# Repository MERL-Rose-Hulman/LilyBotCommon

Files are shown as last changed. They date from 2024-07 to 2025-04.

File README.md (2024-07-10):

# LilyBotCommon
LilyBotCommon is the central repository for shared components and modules used in the Lilybot project. This repository contains common parts and code that are utilized across multiple versions of Lilybot, including those powered by Microbit, Arduino Uno, Raspberry Pi Pico, and Playground Express.

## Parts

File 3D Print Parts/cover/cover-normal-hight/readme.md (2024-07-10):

`cover-normal-height` is compatible with most controllers, including UNO and PICO.

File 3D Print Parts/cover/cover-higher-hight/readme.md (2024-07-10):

`cover-higher-height` is compatible with Micro:bit

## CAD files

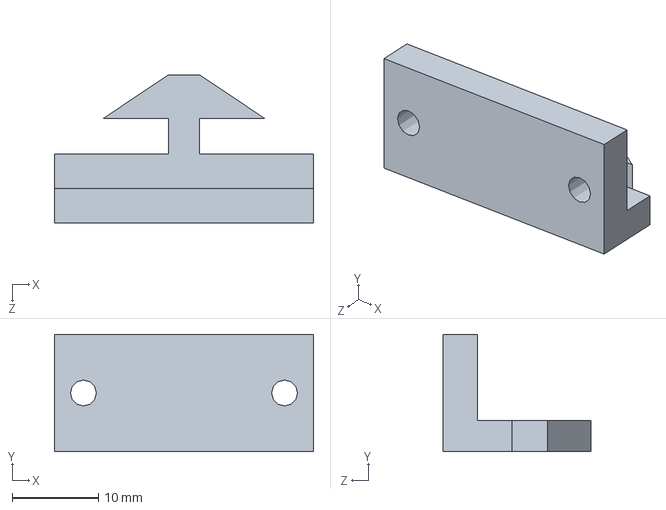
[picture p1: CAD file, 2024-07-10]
3D Print Parts/actuator/gripper/solidworks/Gripper attachment.SLDPRT
30.0 x 13.6 x 17.2 mm

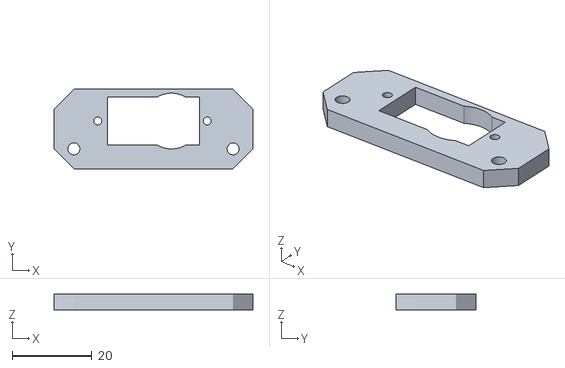
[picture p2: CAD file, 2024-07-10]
3D Print Parts/actuator/gripper/stl/servo-spacer-bigger.stl
50.0 x 20.0 x 4.00

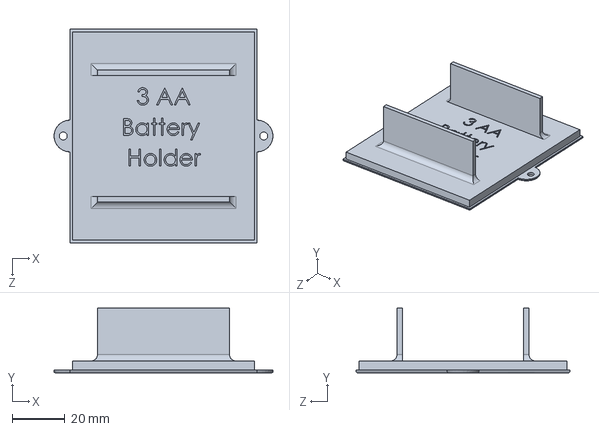
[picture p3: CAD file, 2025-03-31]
3D Print Parts/battery holders/SolidWorks/3AA Battery Holder.SLDPRT
83.0 x 24.5 x 81.0 mm

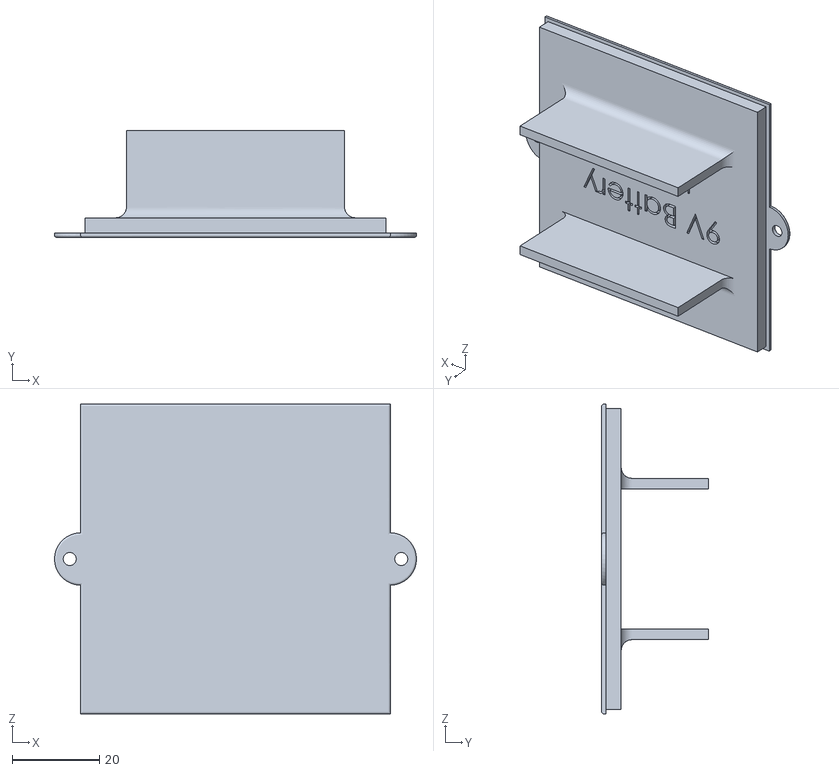
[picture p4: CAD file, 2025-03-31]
3D Print Parts/battery holders/Stl/9V Battery Holder.STL
83.0 x 24.5 x 71.0

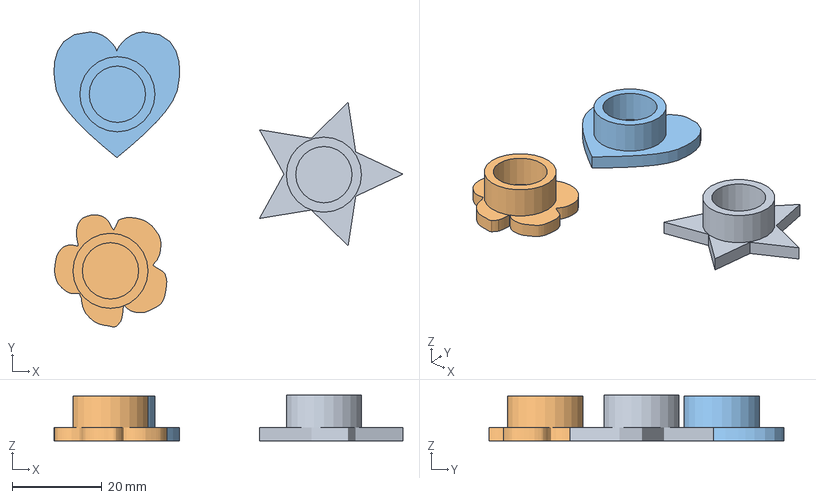
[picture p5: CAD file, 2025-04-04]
3D Print Parts/button hole covers/Printer/Button Hole Covers.3mf
77.8 x 65.7 x 10.2 mm
Star Button Hole Cover.stl
Flower Button Hole Cover.stl
Heart Button Hole Cover.stl

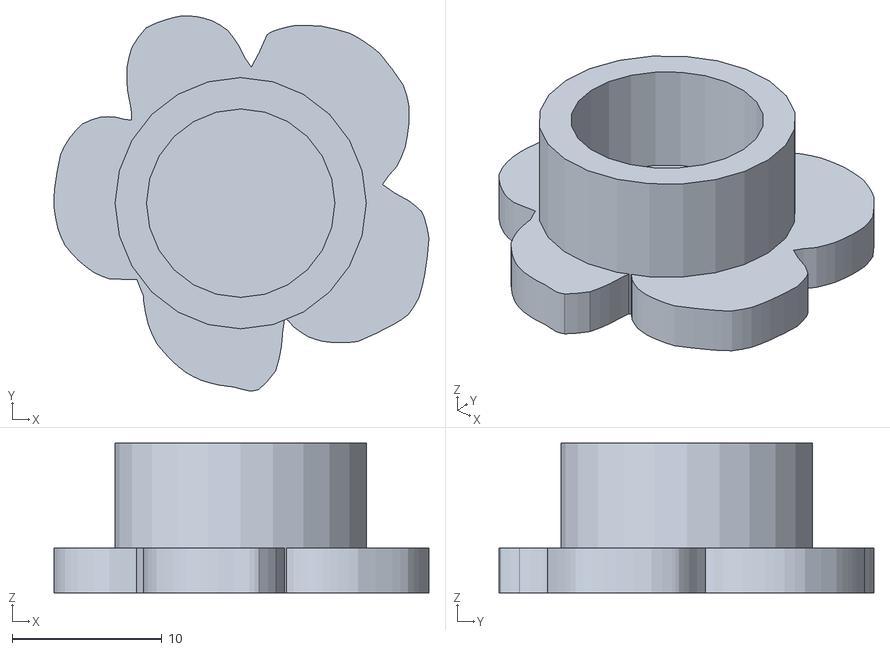
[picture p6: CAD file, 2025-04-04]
3D Print Parts/button hole covers/STL/Flower Button Hole Cover.stl
25.0 x 25.0 x 10.0

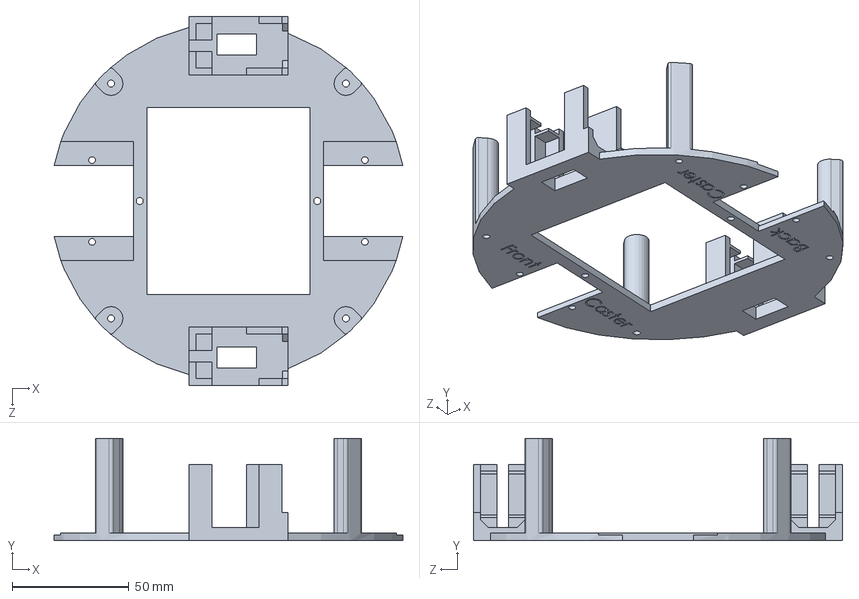
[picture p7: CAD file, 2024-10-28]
3D Print Parts/chassis/bottom/solidworks/Lily Bottom Snap Caster Lifted.SLDPRT
149.3 x 43.8 x 158.0 mm

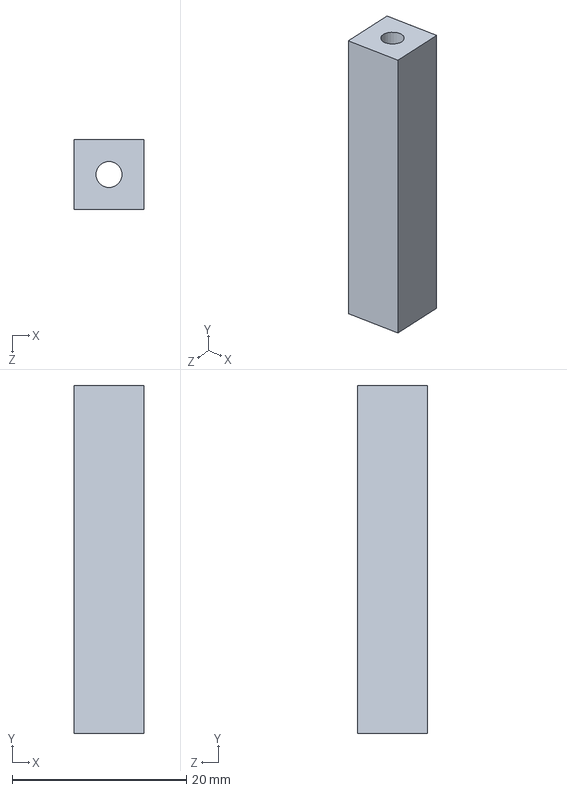
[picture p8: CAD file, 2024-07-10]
3D Print Parts/chassis/NOLONGERUSE/connection/solidworks/Lily standoffs.SLDPRT
8.00 x 40.0 x 8.00 mm

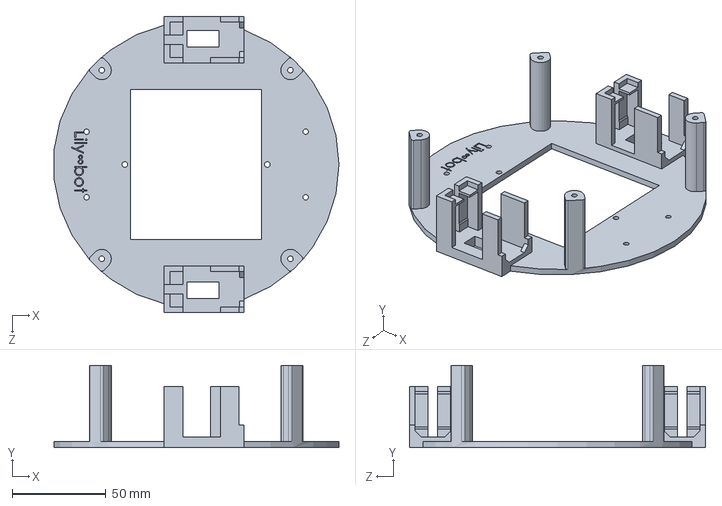
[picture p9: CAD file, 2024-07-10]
3D Print Parts/chassis/NOLONGERUSE/lower/solidworks/Lily Bottom Snap.SLDPRT
152.0 x 43.8 x 158.0 mm

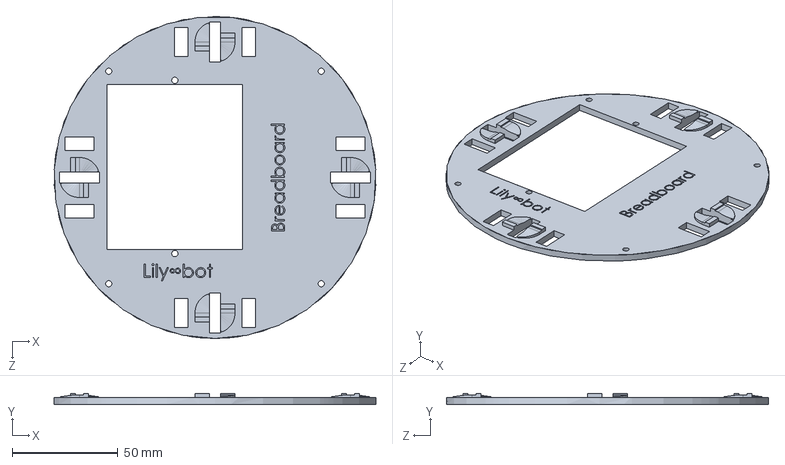
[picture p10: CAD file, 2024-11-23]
3D Print Parts/chassis/top/solidworks/Lily top Flex.SLDPRT
152.2 x 5.08 x 152.4 mm

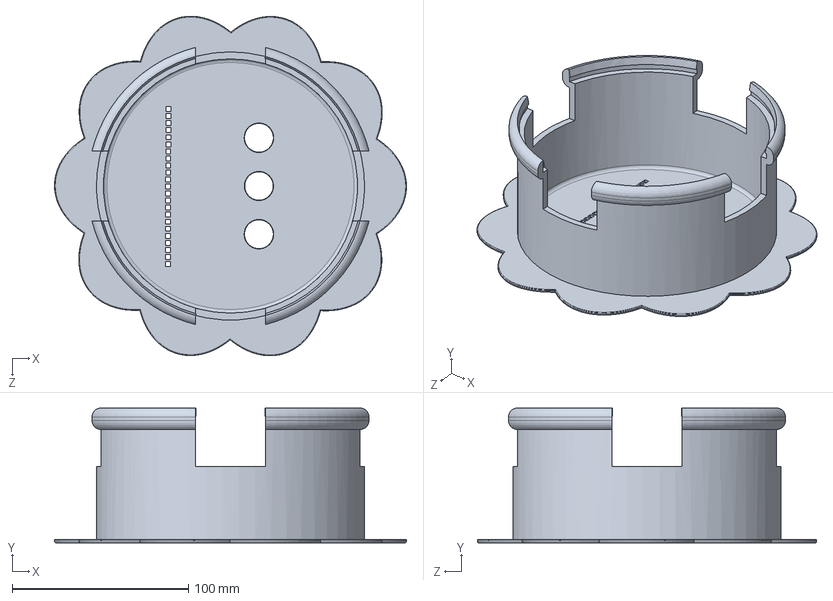
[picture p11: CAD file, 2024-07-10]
3D Print Parts/cover/cover-higher-hight/solidworks/Lily Cover v2.SLDPRT
200.0 x 76.7 x 192.9 mm

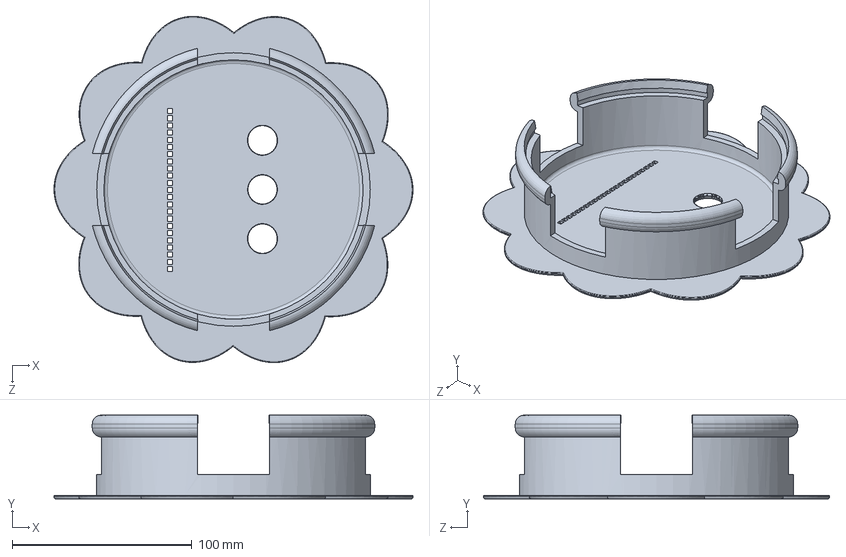
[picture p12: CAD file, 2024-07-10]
3D Print Parts/cover/cover-normal-hight/solidworks/Lily Cover.SLDPRT
200.0 x 46.7 x 192.9 mm

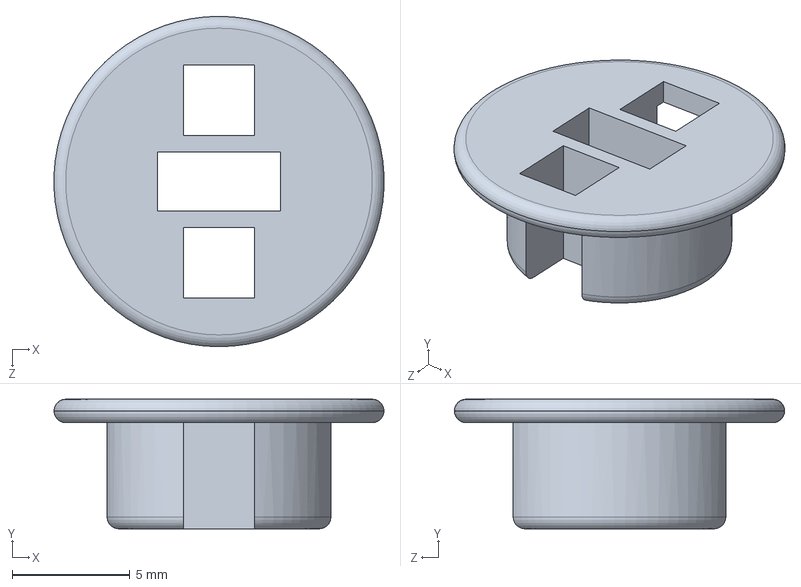
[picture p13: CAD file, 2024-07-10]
3D Print Parts/cover/NOLONGERUSED/cover tablets/solidworks/Lily Cover Hole Tablet Smaller.SLDPRT
14.0 x 5.50 x 14.0 mm

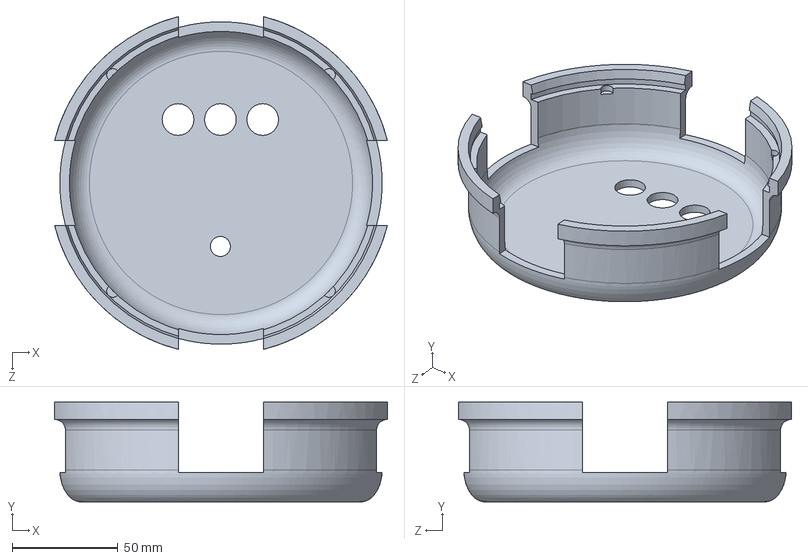
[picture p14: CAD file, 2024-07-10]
3D Print Parts/cover/NOLONGERUSED/cover v1/solidworks/Lily Cover.SLDPRT
157.4 x 47.2 x 157.4 mm

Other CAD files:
3D Print Parts/NOLONGERUSE/motor_mount/solidworks/Motor Mount.SLDPRT
3D Print Parts/NOLONGERUSE/motor_mount/stl/Motor Mount Thick.STL
3D Print Parts/sensor_mount/IR/solidworks/IR sensor Attachment _v2.SLDPRT
3D Print Parts/NOLONGERUSE/motor_mount/solidworks/Motor Mount_V2.SLDPRT
3D Print Parts/NOLONGERUSE/motor_mount/stl/Motor Mount Thin.STL
3D Print Parts/actuator/gripper/stl/GripperAttachment.STL
3D Print Parts/actuator/gripper/stl/finger-bushing-thin.stl
3D Print Parts/actuator/gripper/stl/finger-left-thin.stl
3D Print Parts/actuator/gripper/stl/finger-pad.stl
3D Print Parts/actuator/gripper/stl/finger-right-thin.stl
3D Print Parts/actuator/gripper/stl/gripper-base-thin.stl
3D Print Parts/actuator/gripper/stl/servo-gear.stl
3D Print Parts/actuator/gripper/stl/top-plate-fixed.stl
3D Print Parts/battery holders/SolidWorks/4AA Battery Holder.SLDPRT
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

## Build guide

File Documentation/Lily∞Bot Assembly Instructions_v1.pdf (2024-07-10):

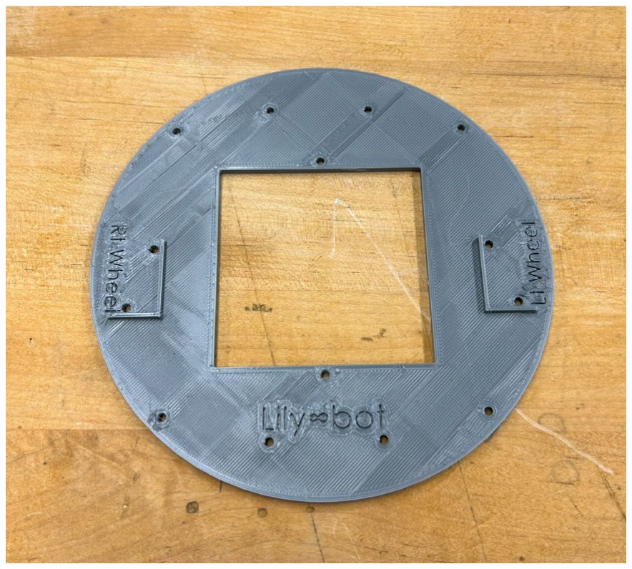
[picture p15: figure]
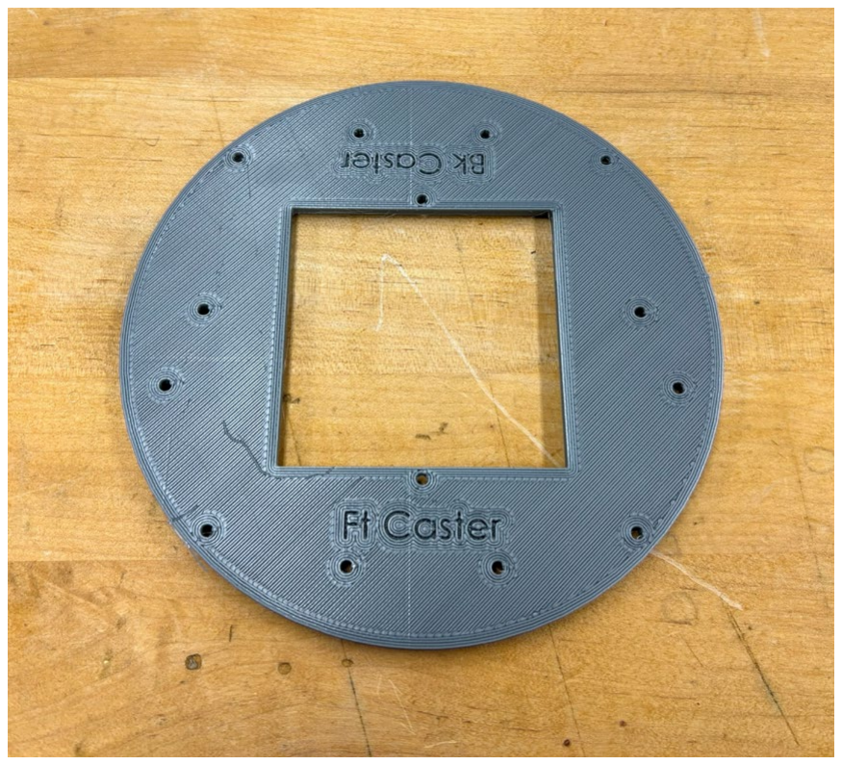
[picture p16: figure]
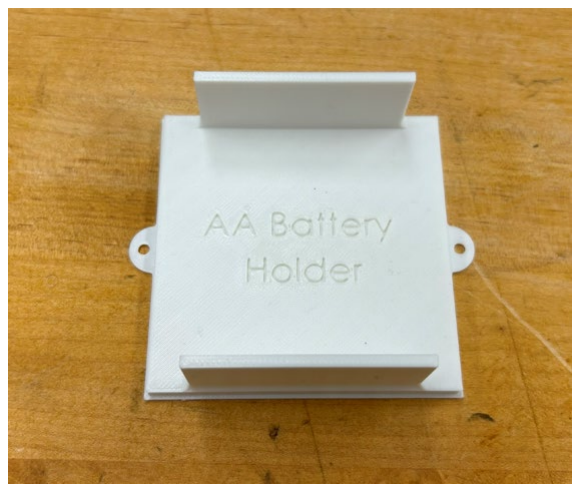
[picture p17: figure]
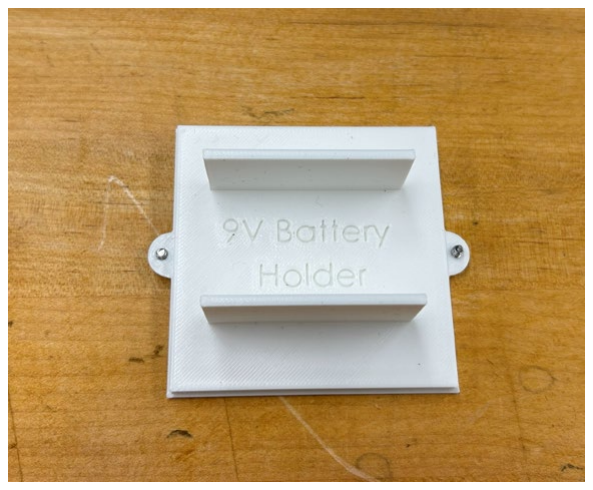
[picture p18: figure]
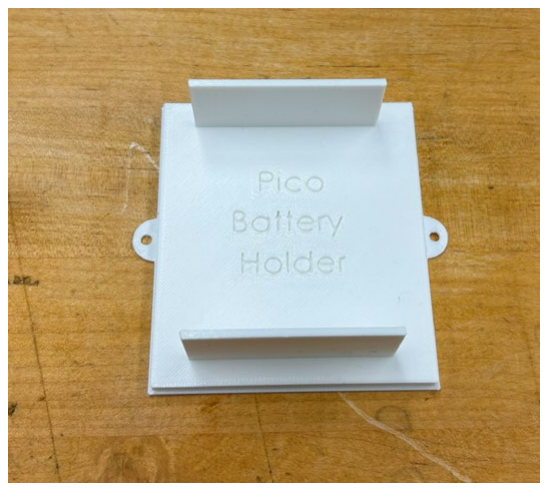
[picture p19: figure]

Version 1: 12/1/23 | Building Lily∞Bot | 1

# Building Lily∞Bot

1. Start by laying out the bottom of the chassis and the battery module that corresponds to your

controller. The AA battery holder is for the Arduino Uno, the 9V battery holder is for the

Microbit, and the Pico battery holder is for the Raspberry Pi Pico.

Figure 1: Top (left) and bottom (right) faces of the bottom chassis

Figure 2: AA Battery holder for the Arduino Uno, 9V battery holder for the Microbit, and the battery

holder for the Raspberry Pi Pico
2. Now that you have your bottom chassis and the right battery holder, let’s start assembling.

This guide uses the 9V battery pack module for its robot. Place your bottom chassis with the

Rt Motor and Lt Motor text facing up and the Ft Caster and Bk Caster text facing down. Take your battery holder and slot it into the chassis from the bottom such that the mounting holes

line up with the holes in the chassis. Figure 3 shows the robot base with a 9V battery pack

module screwed into it.

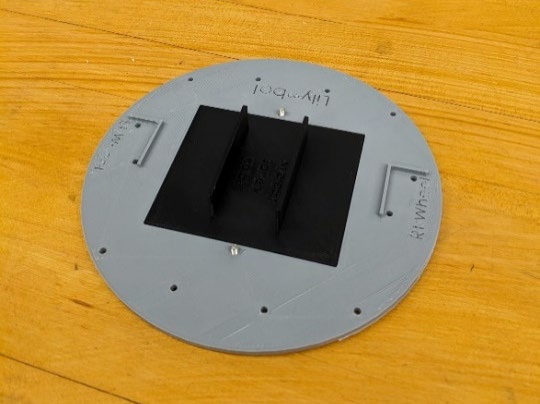
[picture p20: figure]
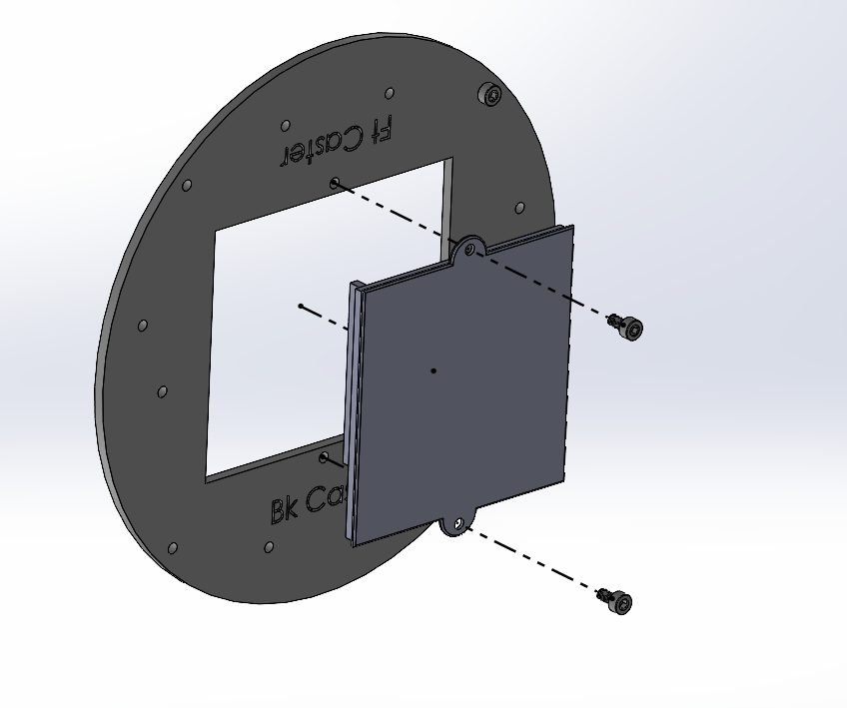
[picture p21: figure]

Figure 3: Bottom base with battery pack module.
3. Get the left and right 3d printed motor mounts and the 2 motors. If not attached, you will

need to use two 10 mm (about 0.39 in) M3 machine screws to attach each motor to the motor

mount. Make sure that the red and black wires point toward the long-slotted end of the

motor mount. Figure 4 shows the right and left motors inserted into the motor mounts with

the 10 mm screws. The figure also shows 2 wheels and four 8 mm (about 0.31 in) M3

mounting screws for attaching the motor mount to the base of the robot.

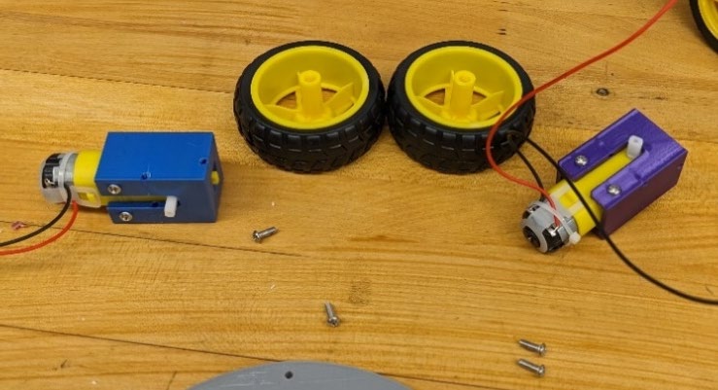
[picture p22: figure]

Figure 4: Wheels, Motors, and Screws.

4. Figure 5 shows the various batteries inserted into their corresponding battery holders. Each

battery pack may be inserted at any time during the robot assembly process. Note that the

robot will ship without batteries.

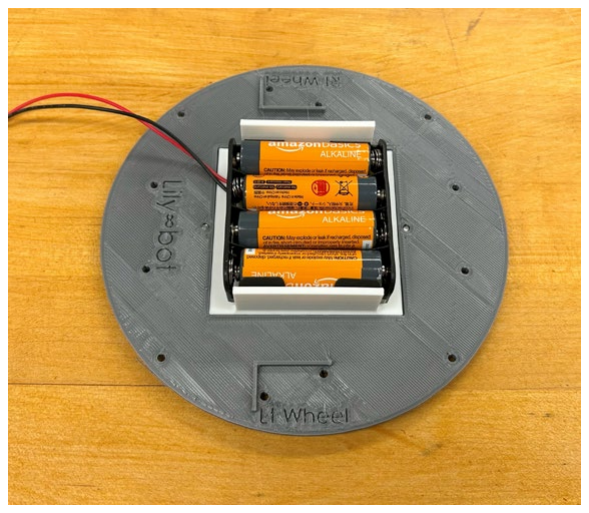
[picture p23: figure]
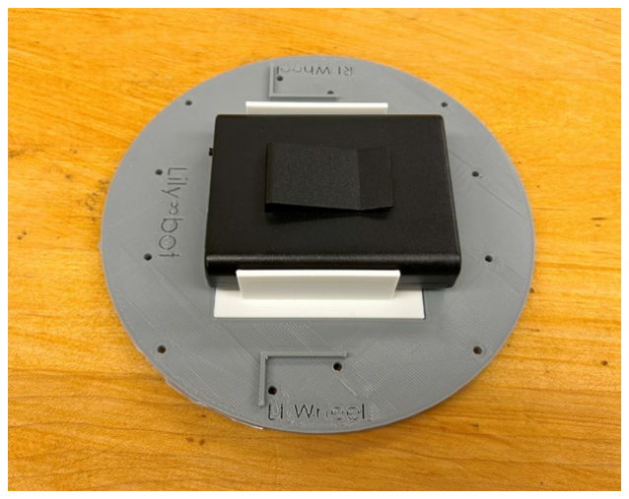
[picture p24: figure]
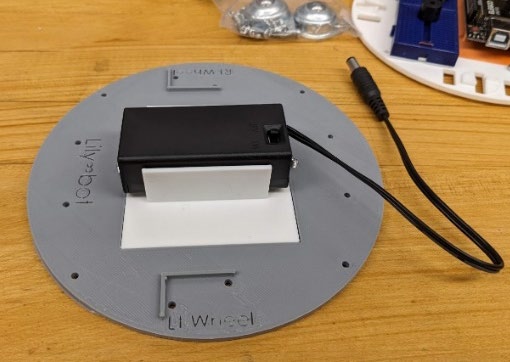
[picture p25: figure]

Figure 5: 9V, Pico, and AA battery packs inserted in battery pack module on robot base
5. The side of each motor should have either an R or an L engraved on it. Starting with the left

motor, place it on the left side of the base (also engraved) such that the wires face the inside

of the robot and the mounting holes on the motor line up with the base. Take one of your

mounting screws, and, using a Phillips head screwdriver, thread it into the bottom of the base

until the head is flush with the base. Repeat with the other screw until the motor is securely

in place. Repeat with the other motor. Figure 6 shows mounting the motors to the robot base.

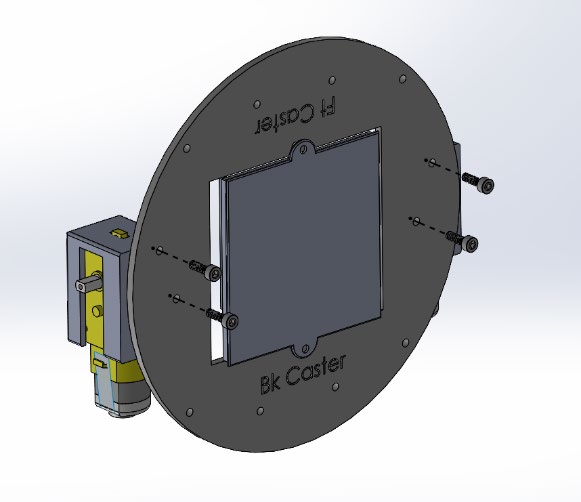
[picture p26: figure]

Figure 6: Attaching the motors to the robot base.
6. Collect 2 caster wheels, 4 M3 screws, 4 M3 nuts, and 4 M3 lock washers as shown in Figure

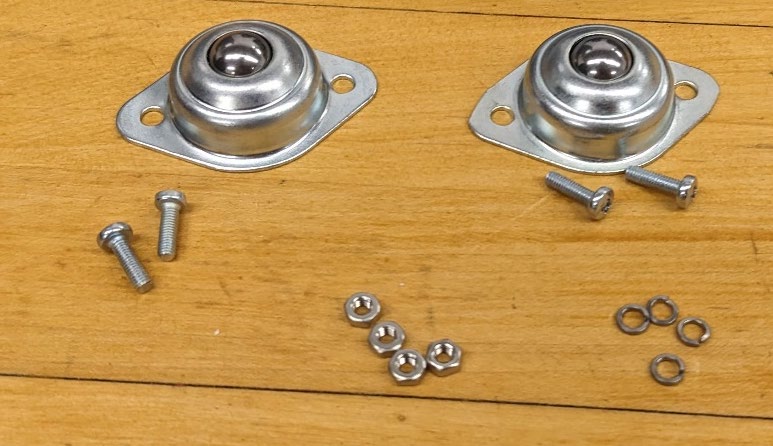
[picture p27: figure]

Figure 7: 2 caster wheels, 4 M3 8 mm (about 0.31 in) screws, 4 M3 lock washers, 4 M3 washers
7. Mount the front caster wheel (labeled on bottom of base) by taking the wheel and placing its

flat side against the bottom of the base. Take each screw and push it through the wheel and

base. Take your lock washer (one for each screw) and place it on the screw. Finally, thread

the nut onto the screw, using a Phillips head screwdriver and appropriate wrench to firmly

secure the wheel in place. Repeat with back caster wheel. Figure 8 shows the steps to attach

the two cater wheels to the bottom robot chassis.

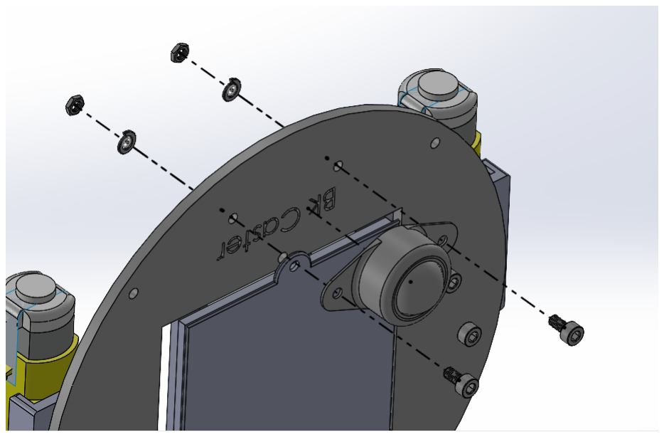
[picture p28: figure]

Figure 8: Attach the caster wheel to the bottom robot chassis using 2 screws, 2 nuts, and 2 lock washers
8. Collect 4 standoffs and 4 8mm (about 0.31 in) M3 machine screws as shown in Figure 9.

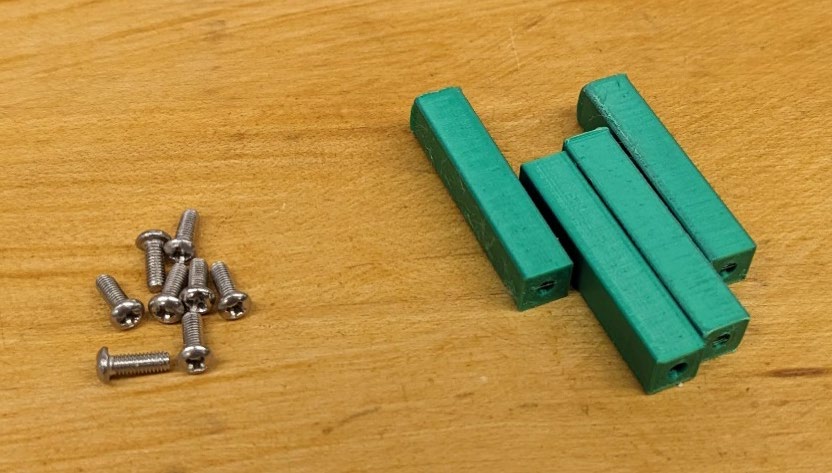
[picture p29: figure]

Figure 9: 4 standoffs and 8 8 mm M3 screws
9. Take one standoff and position it above one of the 4 holes on the outside of the bottom

piece. Take one screw and thread it through the hole, into the standoff from the bottom

of the base. Screw it in carefully, making sure the screw is perpendicular to the base. If

you feel too much resistance, take it out and try again making sure the screw is straight.

Figure 10 shows an example of connecting one standoff to the robot bottom chassis.

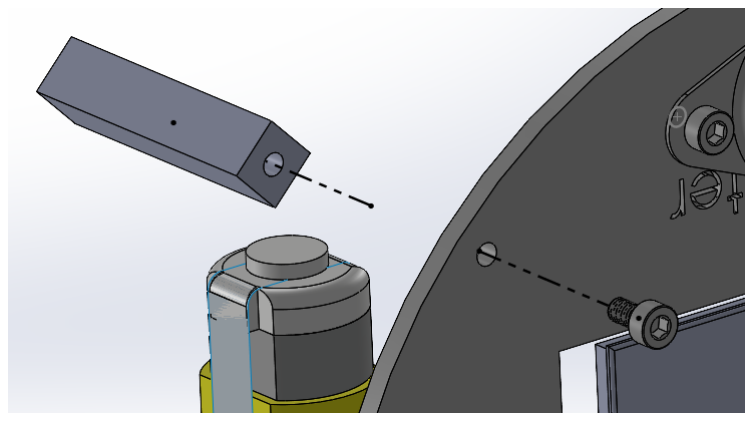
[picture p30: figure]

Figure 10: Connect one standoff to the robot bottom chassis with an 8 mm M3 screw
10. Repeat with the other standoffs, only screwing them in from the base. You should have

4 screws left over when you are done.

11. Retrieve the top chassis for the robot as shown in Figure 11 and attach the

corresponding controller module to it using 2 screws.

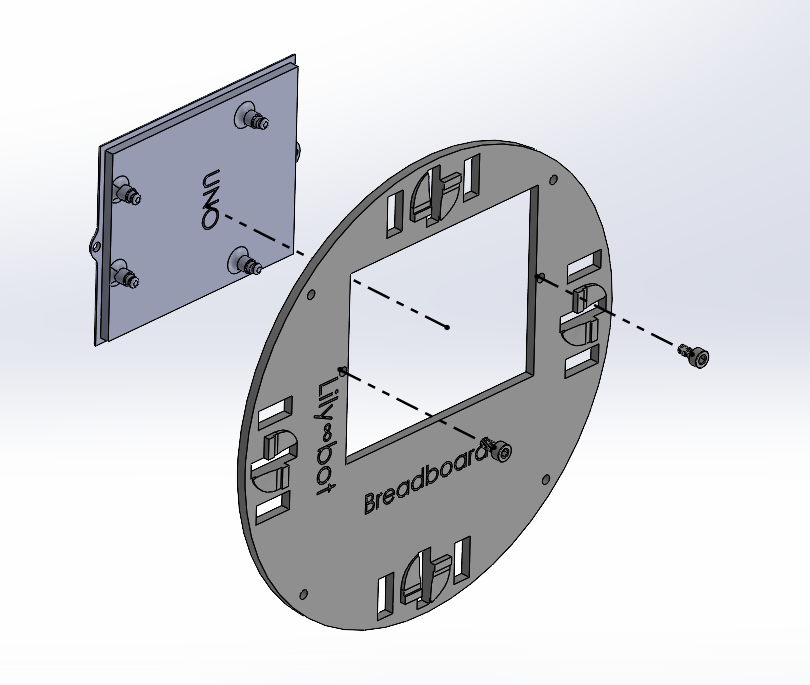
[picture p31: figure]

Figure 11: Screwing the controller mount into the top chassis
12. Some Pico and Uno controller mounts are snap-ons and some have holes to screw into.

For the former, carefully snap the controller in place, lining the holes of the controller

with the mounts and pressing slowly. For the latter, use two 6 mm screws to mount the

controller. Figure 12 shows the Pico and Uno attached to the module with screws.

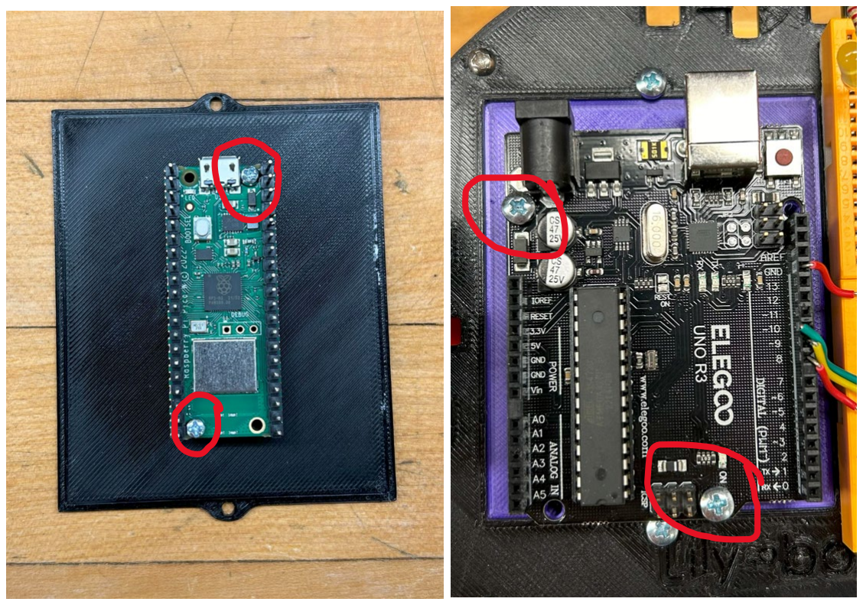
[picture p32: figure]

Figure 12: Pico and Uno microcontrollers screwed into their mounts

13. To install the Microbit, you need to carefully slide the board into the two grooves on the

mount. Push it through such that the board is roughly centered on the mount. Then attach

the vertical board by slotting it into the gold end of the horizontal board.

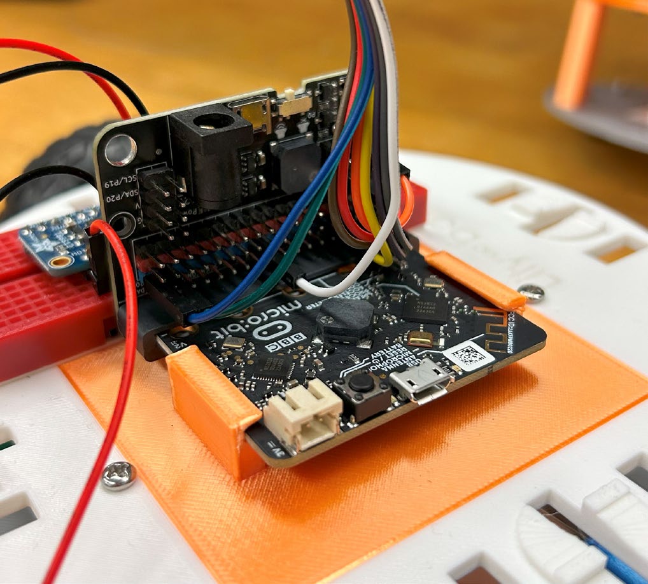
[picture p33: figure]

Figure 13: Installed Microbit controller
14. Next, attach two mini breadboards to the side of the module as shown in Figure 14.

Make sure to not cover any of the sensor or standoff mounting holes.

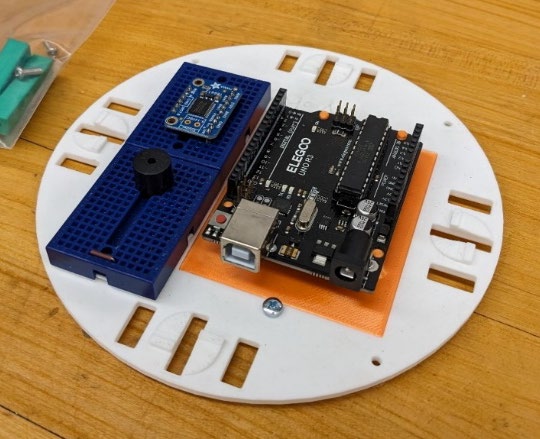
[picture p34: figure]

Figure 14: Upper robot chassis with microcontroller mount, microcontroller, two breadboards, and

TB6612 motor controller installed in breadboard

15. Use the four screws to attach the robot upper chassis to the four standoffs. Make sure

the text is aligned so that the words Lily∞Bot are above each other facing the same

direction. Figure 10 shows the attachment of the four screws to the robot.

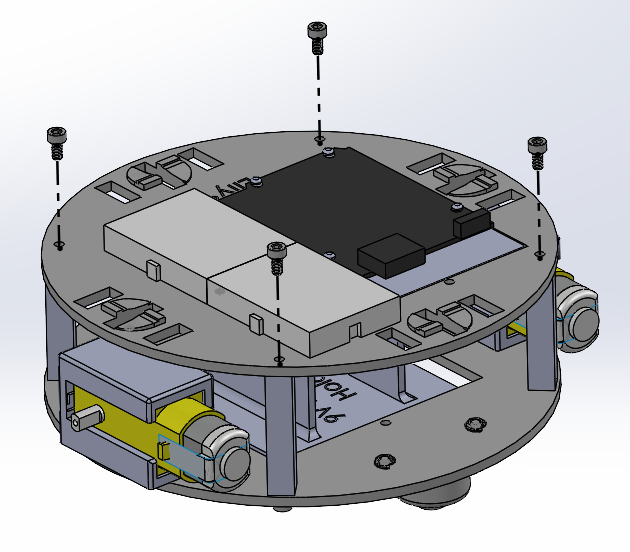
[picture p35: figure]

Figure 15: Attach the robot upper chassis to the bottom chassis with the 4 M3 8 mm machine screws

and standoffs.
16. Finally, attach the two wheels to the DC motors as shown in Figure 16.

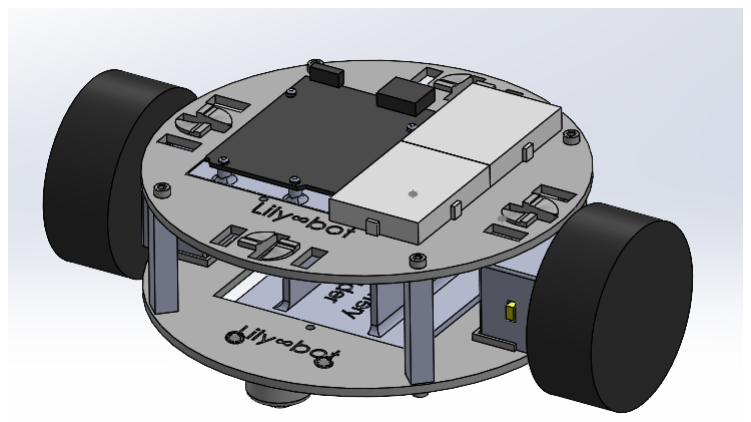
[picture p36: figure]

Figure 16: Two wheels attached to two DC motors on side of Lily∞Bot

# Congratulations Lily∞Bot is Built!

References:

GitHub: | https://github.com/berry123/Lily-Bot
HacksterIO: | https://www.hackster.io/berry123
Instructables: | https://www.instructables.com/member/carlottaberry/
Website: ￼ | https://www.noiresteminist.com/shop
YouTube: | https://www.youtube.com/playlist?list=PL175eO9NwPXICoPyAxInbduXcNKWURqm_

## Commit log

2024-07-10 LilyBot V1 Common
    all the older parts
    [Gripper attachment.SLDPRT, GripperAttachment.STL, IR Attachment .STL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]
2024-07-10 LilyBot 2.0
    Better chassis design, less work on assembling.
    [Lily Bottom Cutout (old).SLDPRT, Lily Bottom Cutted for Motor (old).STL, Lily Bottom Flex (old).STL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]
2024-11-23 Regular Update; Lily bot Location Changed
    [Lily top Flex.SLDPRT, Lily top Flex.STL, Lily top.STL]
2025-03-17 made power bank mount for smaller size
    made power bank mount for smaller size
    [Power Bank Holder.SLDPRT, Power Bank Holder.STL, Power Bank Holder_smaller.SLDPRT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]
2025-03-31 update 4AA battery pack
    updated 4 AA battery pack
    [Power Bank Holder.SLDPRT, Power Bank Holder.STL]
2025-03-31 added battery holders
    added battery holders
    [3AA Battery Holder.SLDPRT, 3AA Battery Holder.STL, 4AA Battery Holder.SLDPRT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]
2025-04-04 added button hole covers to repo
    added button hole covers to repo
    [Button Hole Covers.3mf, Flower Button Hole Cover.stl, Heart Button Hole Cover.stl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]
2025-04-16 updated 3.3V sonar mount
    [Sonar_3V Attachment.SLDPRT, Sonar_3V Attachment.STL]
2025-04-16 updated 5V sonar mount
    [Sonar Attachment .STL, Sonar Attachment.SLDPRT, Sonar_5V Attachment.SLDPRT]
2025-05-02 update IR and photo sensors
    update IR and photo sensors
    [4AA Battery Holder.3mf, IR sensor Attachment _v2.SLDPRT, IR sensor Attachment_v2.STL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]
2025-05-09 Update Sonar Mount Solidworks
    [Sonar_3V Attachment.SLDPRT, Sonar_5V Attachment.SLDPRT]
2025-06-22 Create Power Bank Holder.3mf
    [Power Bank Holder.3mf]
2025-10-16 updated sonar mount
2025-11-11 added large power bank holder
    added large power bank holder
2026-10-26 added extra support to motor holder on the side
2026-10-26 Rename 3D Print Parts/battery holders/SolidWorks/Power Bank Holder.SLDPRT to 3D Print Parts/battery holders/SolidWorks/Power Bank Holder_OCT26/2026.SLDPRT
2026-10-26 Rename 2026.SLDPRT to Power Bank Holder_OCT26_2026.SLDPRT
2026-10-26 Rename 3D Print Parts/battery holders/SolidWorks/9V Battery Holder New_mod_Oct_2026.SLDPRT to 3D Print Parts/battery holders/SolidWorks/Power Bank Holder_OCT26/9V Battery Holder New_mod_Oct_2026.SLDP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
2026-10-26 Rename 3D Print Parts/battery holders/SolidWorks/Power Bank Holder_smaller.SLDPRT to 3D Print Parts/battery holders/SolidWorks/Power Bank Holder_OCT26/Power Bank Holder_smaller.SLDPRT
2026-10-26 Rename Power Bank Holder_smaller.SLDPRT to Power Bank Holder_smaller_Oct26_2026.SLDPRT
2026-10-28 Added support to motor holder
